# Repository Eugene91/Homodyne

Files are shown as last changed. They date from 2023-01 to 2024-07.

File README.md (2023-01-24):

# Optical Homodyne detector
The design is done with Kicad 6.0 and is based on the [Optics Communications, 285(24), 5259-5267](https://www.sciencedirect.com/science/article/abs/pii/S0030401812008255).
## Few details
- The detector is designed for [First Sensor PS1.0-6B Photodetectors](https://www.mouser.ca/datasheet/2/313/PS1.0-6b_TO_501429-586466.pdf) photodiodes, but may also work with [Hamamatsu S5972](https://www.hamamatsu.com/eu/en/product/type/S5972/index.html).
- The detector is power by ± 15 Volts that are spitted on 4 Voltage variable regulators LM337 and LM317. 
- Two regulators are used to power the 4.7 kOhm transimpedance that is based on OPA 847 with effective bandwidth 3 dB of 100 MHz
- Two reversely biased photodiodes are separately biased my other two voltage regulators.
- Compensation capacitor C18 is used to prevent oscillations of the OPA847 and is in situ adjusted within a range of 1-4pF.

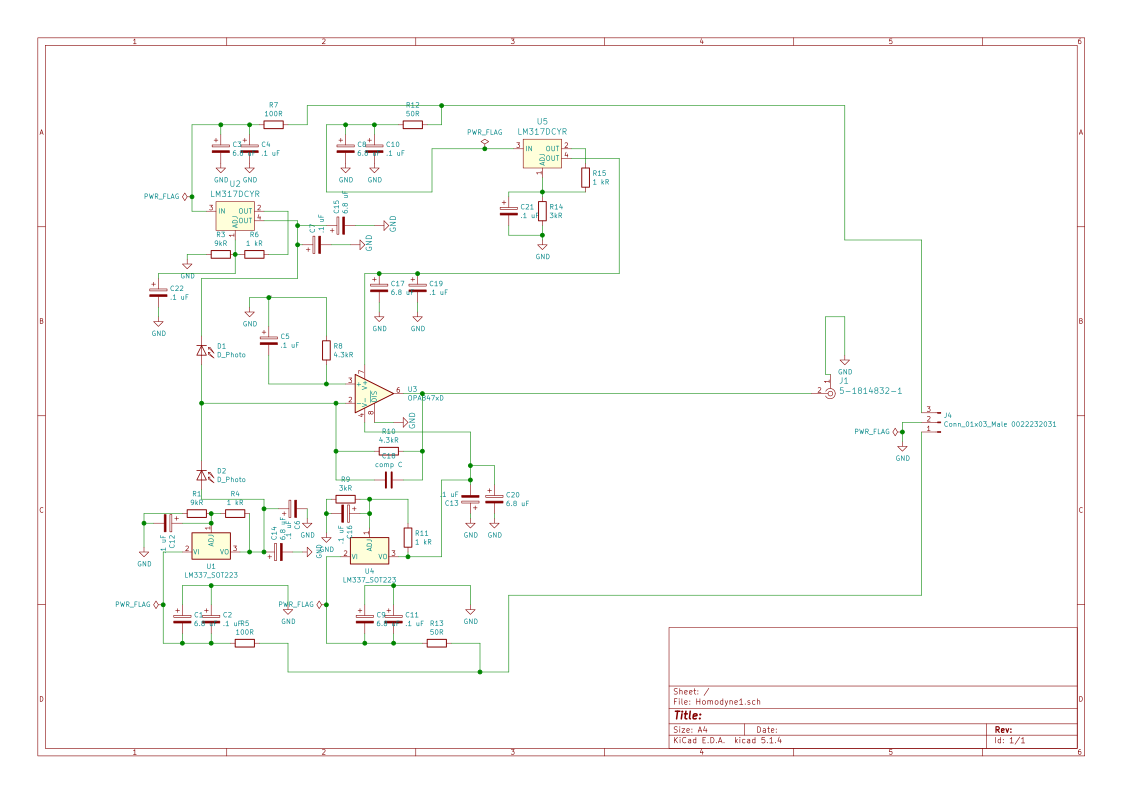
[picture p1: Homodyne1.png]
Schematics


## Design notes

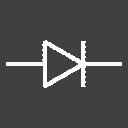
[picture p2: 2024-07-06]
diode-small.png

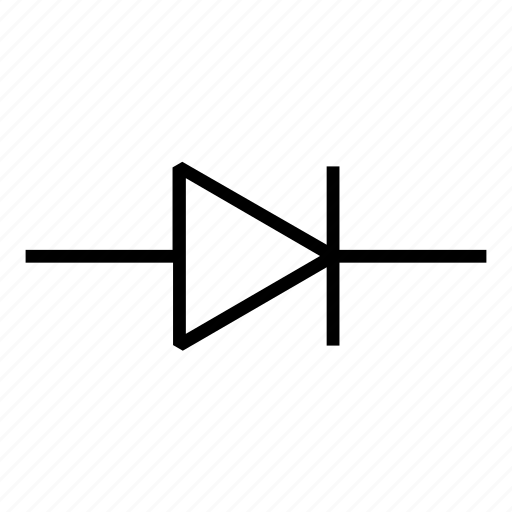
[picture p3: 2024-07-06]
diode.png

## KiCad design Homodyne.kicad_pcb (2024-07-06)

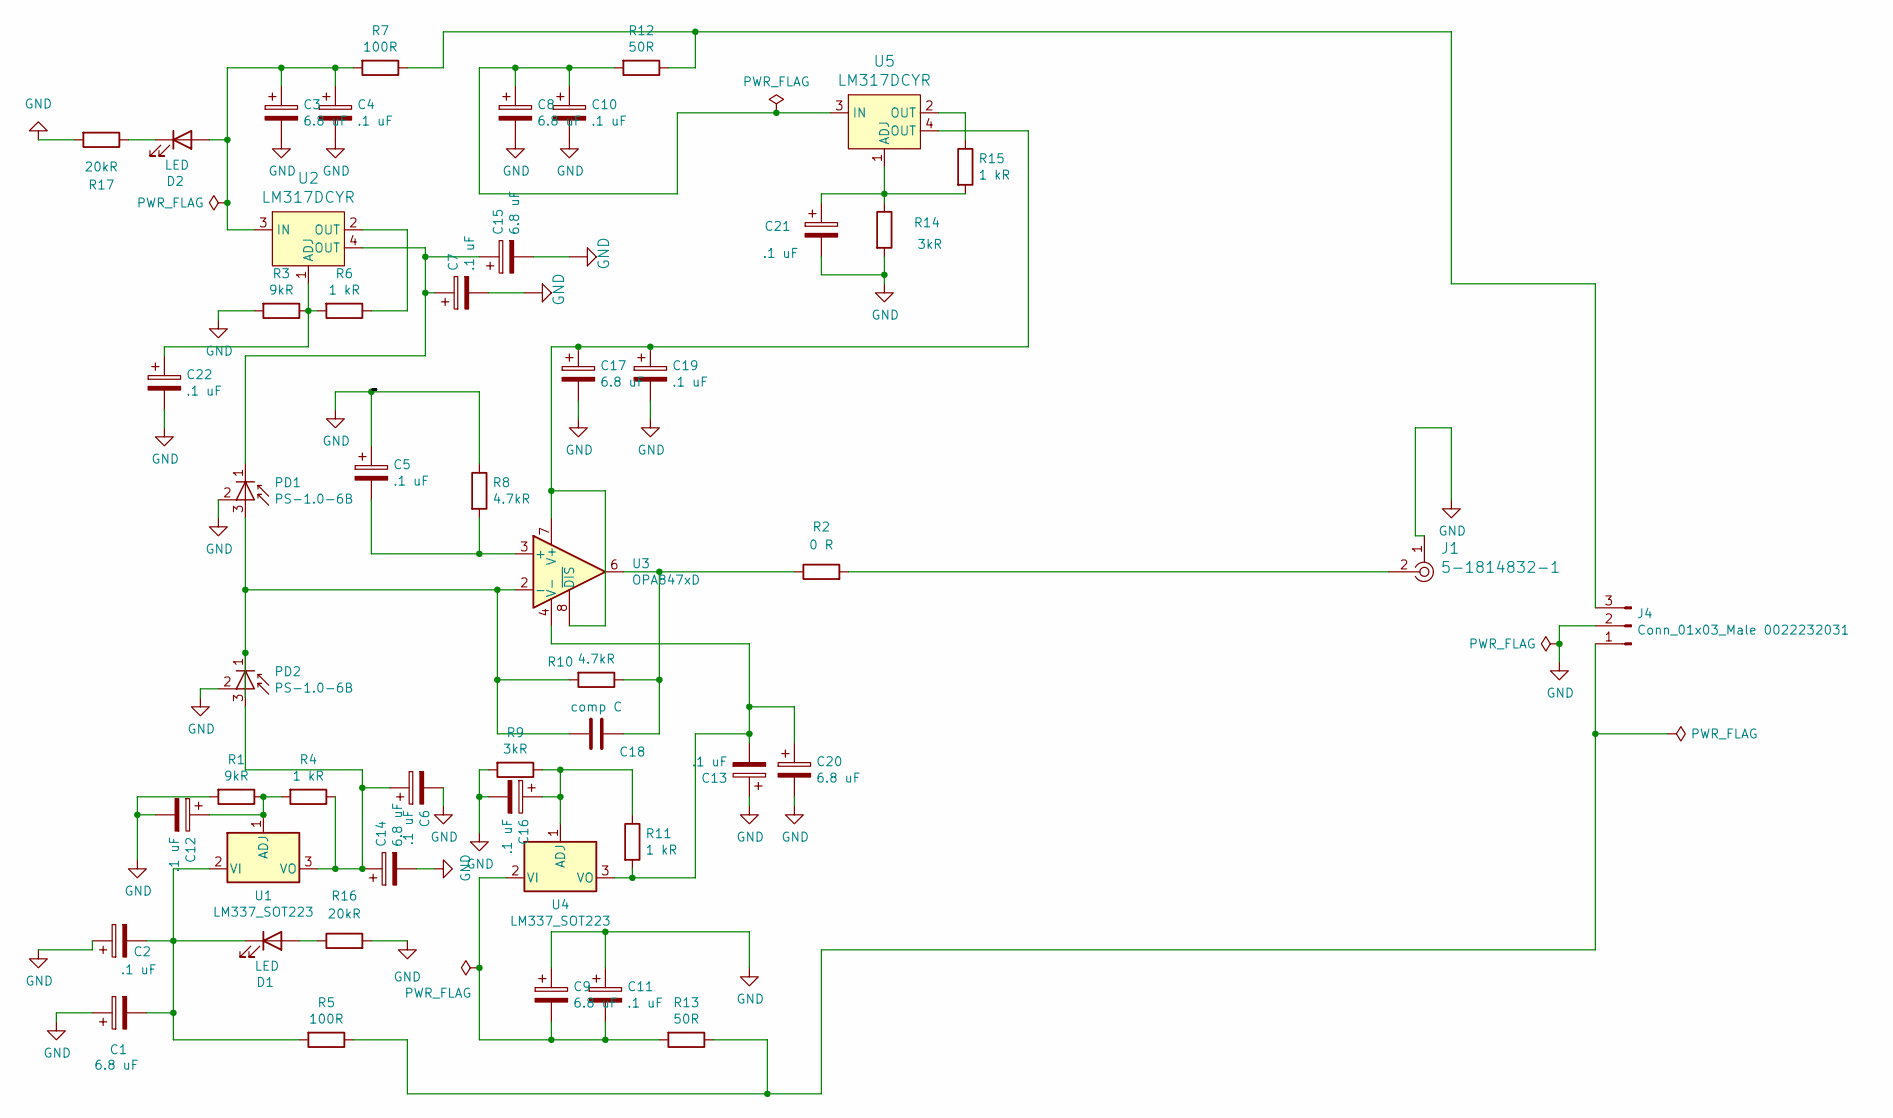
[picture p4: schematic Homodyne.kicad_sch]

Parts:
C1, C3, C8, C9, C14, C15, C17, C20: 6.8 uF; C_1206
C2, C4, C5, C6, C7, C10, C11, C12, C13, C16, C19, C21, C22: .1 uF; C_1206
C18: comp C; C_0603
D1, D2: LED; LED_1206_3216Metric
J1: 5-1814832-1; RF_SMA_Vertical_5-1814832-1; MPN 5-1814832-1; Digi-Key_PN A97594-ND
J4: Conn_01x03_Male 0022232031; PinHeader_1x03_P2.54mm_Vertical
PD1, PD2: PS-1.0-6B; TO-52-3
R1, R3: 9kR; R_1206_3216Metric
R2: 0 R; R_1206_3216Metric
R4, R6, R11, R15: 1 kR; R_1206_3216Metric
R5, R7: 100R; R_1206_3216Metric
R8, R10: 4.7kR; R_1206_3216Metric
R9, R14: 3kR; R_1206_3216Metric
R12, R13: 50R; R_1206_3216Metric
R16, R17: 20kR; R_1206_3216Metric
U1, U4: LM337_SOT223; SOT-223-3_TabPin2
U2, U5: LM317DCYR; SOT-223; MPN LM317DCYR; Digi-Key_PN 296-12602-1-ND
U3: OPA847xD; SOIC-8_3.9x4.9mm_P1.27mm

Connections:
GND: C1.1, C2.1, C3.2, C4.2, C5.1, C6.2, C7.2, C8.2, C9.1, C10.2, C11.1, C12.2, C13.1, C14.2, C15.2, C16.2, C17.2, C19.2, C20.2, C21.2, C22.2, J1.1, J4.2, PD1.2 (CASE), PD2.2 (CASE), R1.2, R3.2, R8.1, R9.2, R14.2, R16.2, R17.2
unnamed: C18.1, R2.1, R10.1, U3.6
unnamed: D1.2 (A), R16.1
unnamed: C1.2, C2.2, D1.1 (K), R5.2, U1.2 (VI)
unnamed: C3.1, C4.1, D2.2 (A), R7.2, U2.3 (IN)
unnamed: D2.1 (K), R17.1
unnamed: J1.2, R2.2
unnamed: J4.1, R5.1, R13.1
unnamed: J4.3, R7.1, R12.1
unnamed: C18.2, PD1.3 (A), PD2.1 (K), R10.2, U3.2 (-)
unnamed: C7.1, C15.1, PD1.1 (K), U2.4 (OUT)
unnamed: C6.1, C14.1, PD2.3 (A), R4.1, U1.3 (VO)
unnamed: R6.1, U2.2 (OUT)
unnamed: R15.1, U5.2 (OUT)
unnamed: C12.1, R1.1, R4.2, U1.1 (ADJ)
unnamed: C22.1, R3.1, R6.2, U2.1 (ADJ)
unnamed: C5.2, R8.2, U3.3 (+)
unnamed: C17.1, C19.1, U3.7 (V+), U3.8 (~DIS), U5.4 (OUT)
unnamed: C13.2, C20.1, R11.2, U3.4 (V-), U4.3 (VO)
unnamed: C16.1, R9.1, R11.1, U4.1 (ADJ)
unnamed: C9.2, C11.2, R13.2, U4.2 (VI)
unnamed: C21.1, R14.1, R15.2, U5.1 (ADJ)
unnamed: C8.1, C10.1, R12.2, U5.3 (IN)

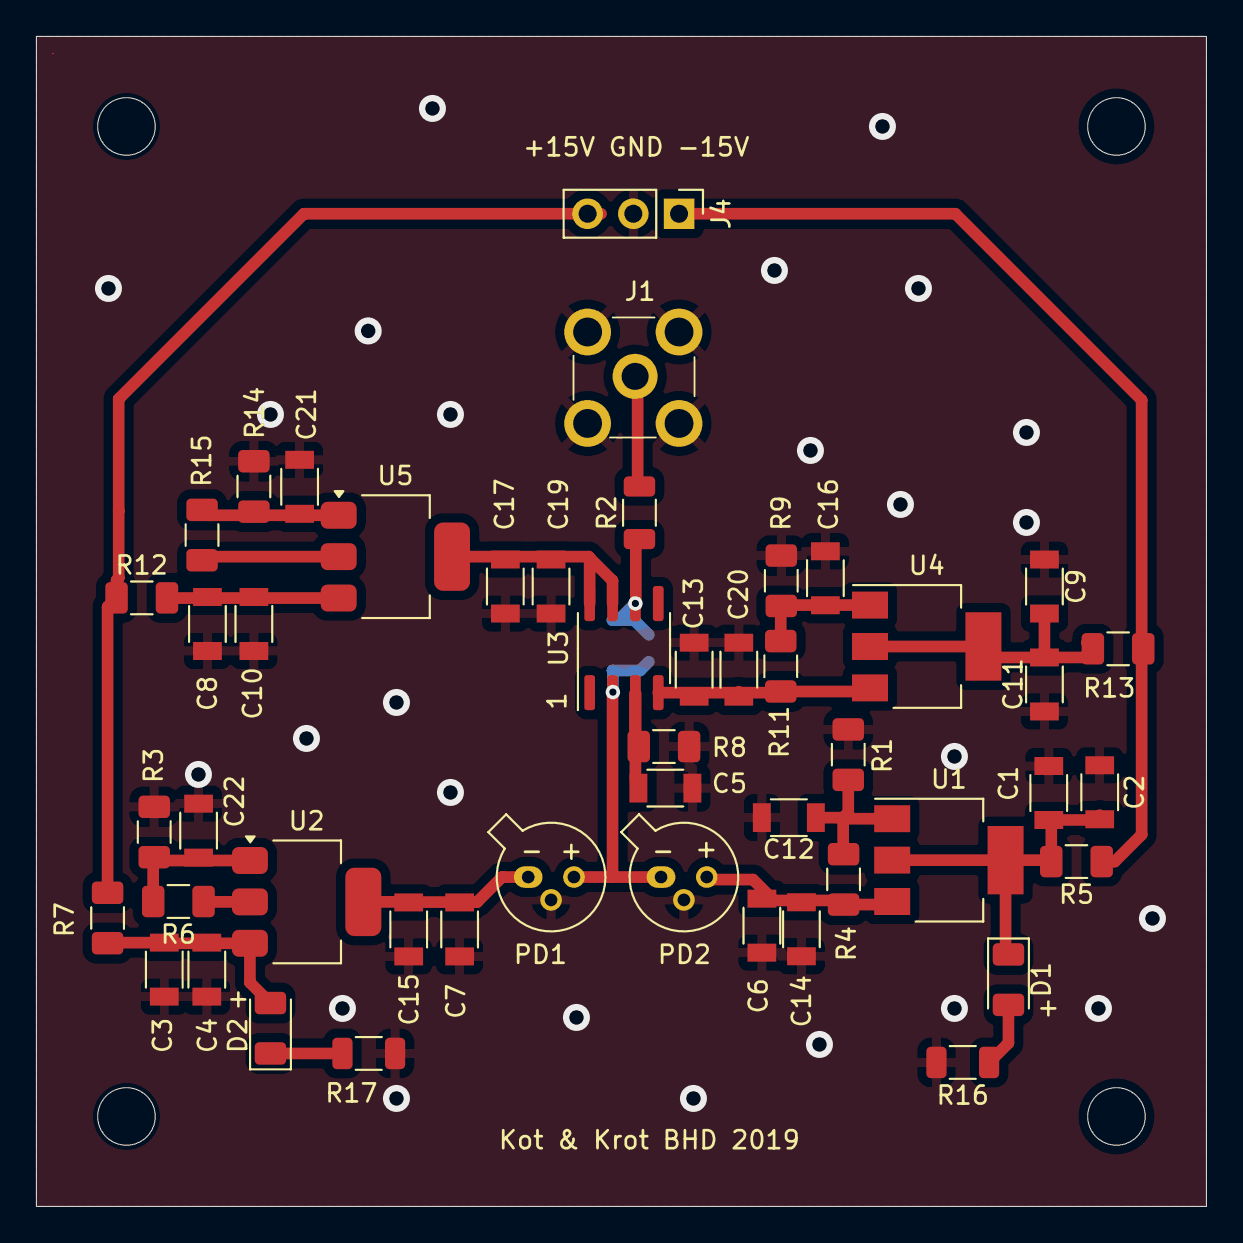
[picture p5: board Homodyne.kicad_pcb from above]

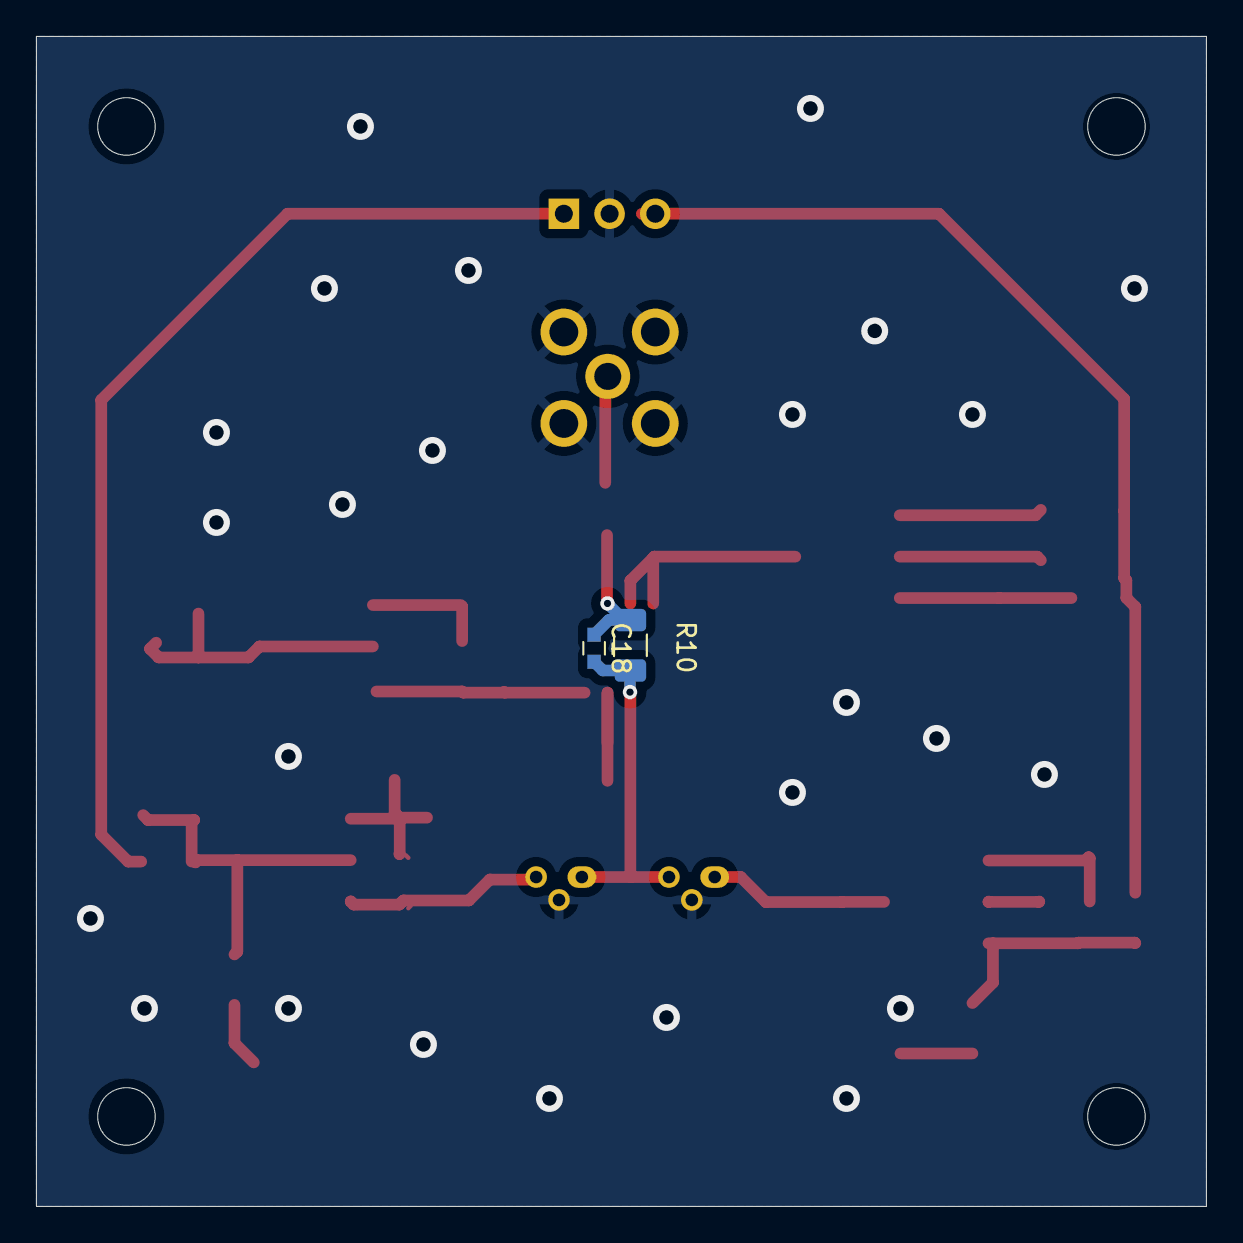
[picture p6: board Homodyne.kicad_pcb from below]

Board: 2 copper layers, 65.0 x 65.0 mm, 50 parts (2 on the bottom side), 23 nets.

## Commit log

2023-01-23 v 0.1
    [Homodyne.kicad_pcb, Homodyne.kicad_sch]
2023-01-24 Small fix
    [Homodyne.kicad_sch]
2024-07-06 Updated the board size to 65x65 mm
    [Homodyne-B_Cu.gbl, Homodyne-B_Mask.gbs, Homodyne-B_Paste.gbp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]
